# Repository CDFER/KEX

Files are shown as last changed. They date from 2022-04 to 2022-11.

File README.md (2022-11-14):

# Currently not maintained or tested, use at your own risk

## KEX a Rapid Deployment ESP32 Board
A fast and feature-rich implementation of an ESP32 board with NeoPixel Led (WS2812B, WS2811, SK6812), I2S (Digital microphone) and I2C outputs.

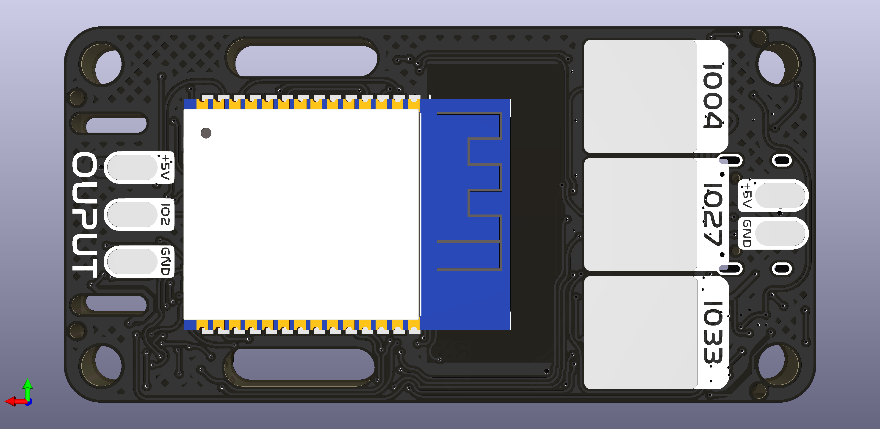
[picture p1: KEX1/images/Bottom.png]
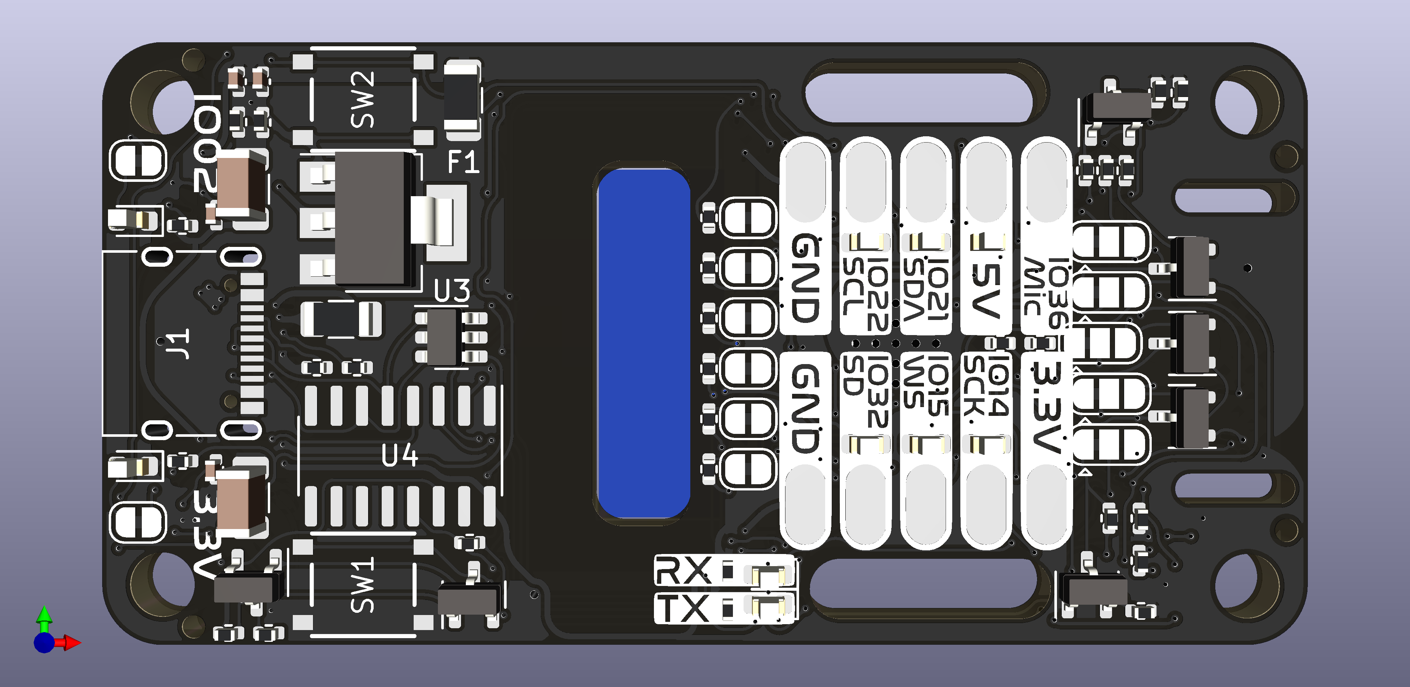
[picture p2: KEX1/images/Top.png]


## ⚙️ Features
- Supports USB C to USB C cables at 5V 3A 
- 3 Capacitive Touch Buttons
- Designed for PCB Assembly by JLCPCB 
- 3A Resettable Fuse on both the 3.3v and 5v Rails
- Programming using the CH340-c IC
- Electrostatic Discharge Protection on USB and LED Output
- Auto Reset for easy programming
- Solder Pad connections with Strain relief slots 
- High-Speed Bi-Directional Level shifted I2S and I2C ports using BSS138 like [Adafruit](https://www.adafruit.com/product/757)
- Cuttable solder pads to select between 3.3v and 5v level shifting
- LED indicators on all outputs and inputs
- Easy soldering of led strips directly to the PCB with Strain Releaf slots

## 📲 Quickstart
1. Solder the ESP32 to the footprint on the PCB

2. Connect up to 120 NeoPixels (WS2812B, WS2811, SK6812) to the output pads (IO2). 
3. Install the CH340 Drivers from [Sparkfun](https://learn.sparkfun.com/tutorials/how-to-install-ch340-drivers/all)
4. Flash the software to your ESP module! There are two options for this step:
  
&nbsp;&nbsp;&nbsp;&nbsp;&nbsp;&nbsp;[I just want to use WLED! (install release binary)](https://install.wled.me/)

&nbsp;&nbsp;&nbsp;&nbsp;&nbsp;&nbsp;[I want to modify WLED (compile from source code)](https://kno.wled.ge/advanced/compiling-wled/)

&nbsp;&nbsp;&nbsp;&nbsp;&nbsp;&nbsp;If set up correctly, the first thirty LEDs will light up!

5. Use a Computer/Phone to connect to the Wife named: WLED-AP using the password wled1234.

6. Click on the cog icon to edit settings like connecting the module to your home WiFi.
7. Upload Config File (Coming soon...)

## 💾 Pinout
Pin | IO2 | IO4 | IO14 | IO15 | IO21 | IO22 | IO27 | IO32 | IO33 | IO36
--- | --- | --- | --- |--- |--- |--- |--- |--- |--- |---
Usage | LED Output | Down Touch Pad | SCK | WS | SDA | SCL | Middle Touch Pad | SD |  Up Touch Pad | Analog Input 
LED | Yellow | | White | White | Red | Green | | White | | |
Level Shifted | | |✅|✅|✅|✅| |✅| 

## ✌️ Other

[Licensed under the MIT license](https://github.com/git/git-scm.com/blob/main/MIT-LICENSE.txt)

Designed by Chris Dirks (@CD_FER)

You can also send me emails to [cdirksfer@gmail.com](mailto:dev.cdirksfer@gmail.com), but please only do so if you want to talk to me privately.

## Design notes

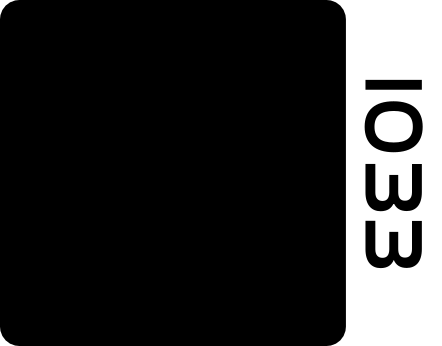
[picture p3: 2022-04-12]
KEX1/PCB V1/Graphics/IO33.png

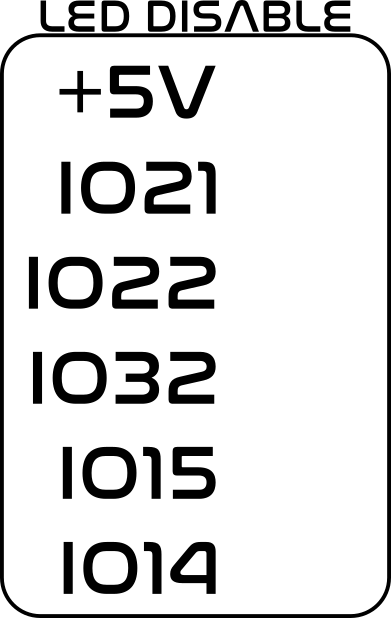
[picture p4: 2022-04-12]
KEX1/PCB V1/Graphics/g134261.png

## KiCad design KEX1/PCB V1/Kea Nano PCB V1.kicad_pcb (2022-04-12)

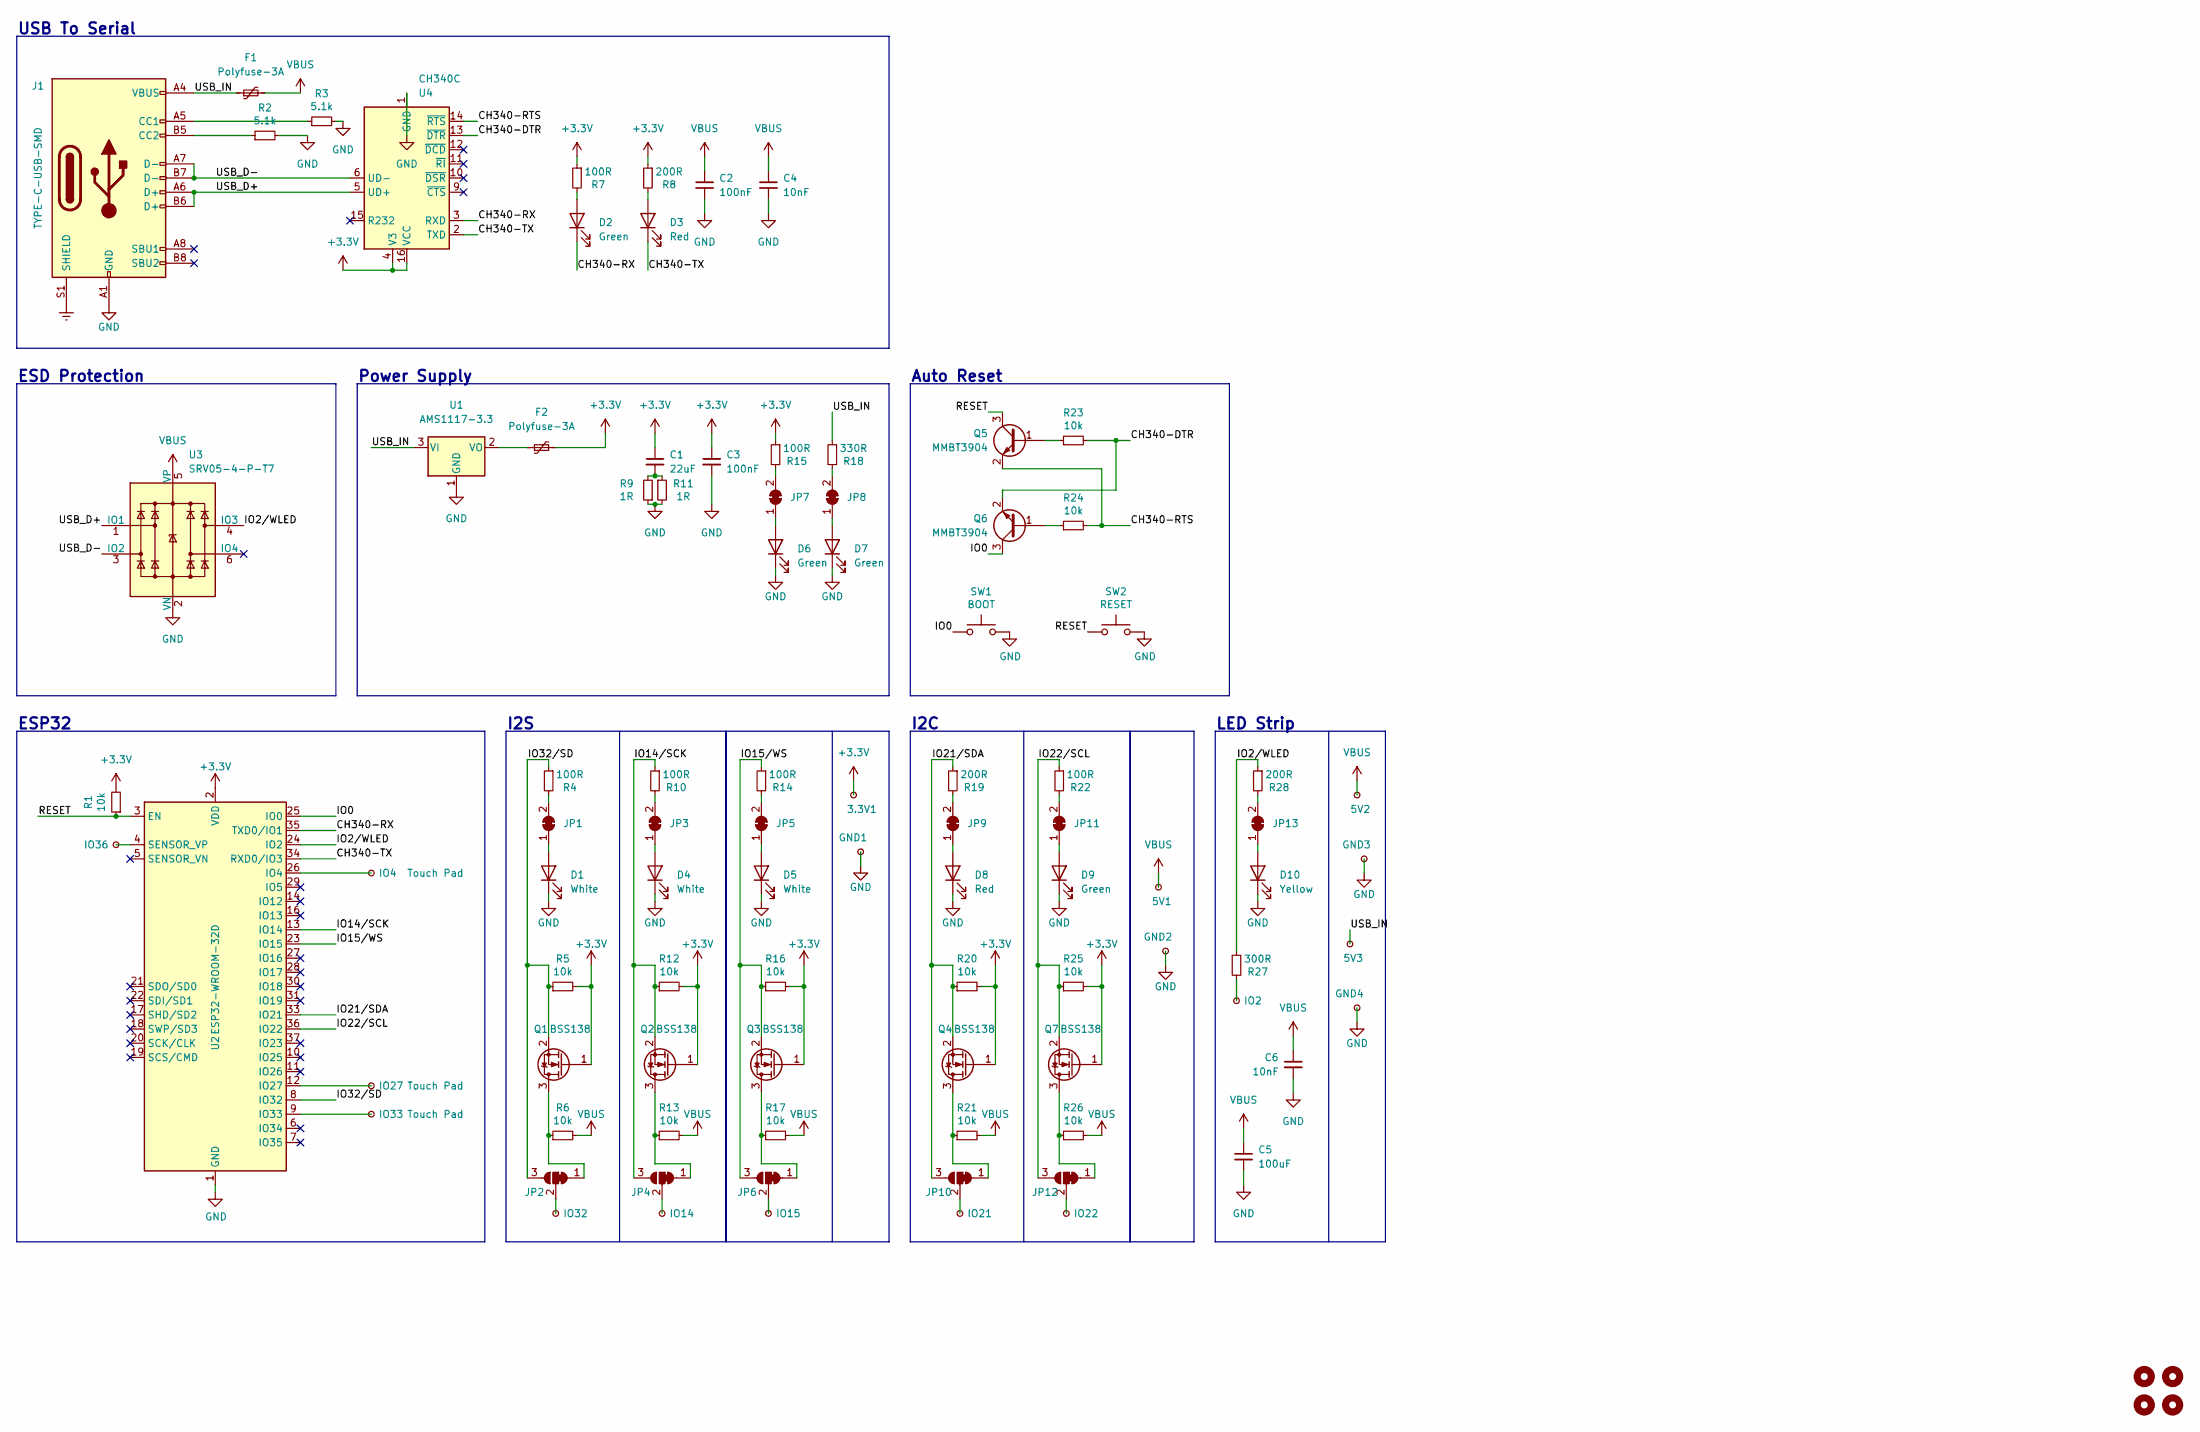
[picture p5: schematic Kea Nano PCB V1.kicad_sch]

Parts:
3.3V1, 5V1, 5V2, 5V3: IO; IO Pad
C1: 22uF; C_1206_3216Metric; LCSC C5672
C2, C3: 100nF; C_0402_1005Metric; LCSC C1525
C4, C6: 10nF; C_0402_1005Metric; LCSC C15195
C5: 100uF; C_1206_3216Metric; LCSC C15008
D1, D4, D5: White; LED_0603_1608Metric; LCSC C2290
D2, D6, D7, D9: Green; LED_0603_1608Metric; LCSC C72043
D3, D8: Red; LED_0603_1608Metric; LCSC C2286
D10: Yellow; LED_0603_1608Metric; LCSC C72038
F1, F2: Polyfuse-3A; Fuse_1206_3216Metric; LCSC C516068
GND1, GND2, GND3, GND4: IO; IO Pad
H1, H2, H3, H4: MountingHole; MountingHole_3.2mm_M3_DIN965
IO2, IO14, IO15, IO21, IO22, IO32, IO36: IO; IO Pad
IO4: Touch Pad; Touch Pad ST
IO27, IO33: Touch Pad
J1: TYPE-C-USB-SMD; USB_C_Receptacle_XKB_U262-16XN-4BVC11; LCSC C167321
JP1, JP3, JP5, JP7, JP8, JP9, JP11, JP13: SolderJumper_2_Bridged; SolderJumper-2_P1.3mm_Bridged_RoundedPad1.0x1.5mm
JP2, JP4, JP6, JP10, JP12: SolderJumper_3_Bridged12; SolderJumper-3_P1.3mm_Bridged12_RoundedPad1.0x1.5mm
Q1, Q2, Q3, Q4, Q7: BSS138; SOT-23; LCSC C78284
Q5, Q6: MMBT3904; SOT-23; LCSC C20526
R1, R5, R6, R12, R13, R16, R17, R20, R21, R23, R24, R25, R26: 10k; R_0402_1005Metric; LCSC C25744
R2, R3: 5.1k; R_0402_1005Metric; LCSC C25905
R4, R7, R10, R14, R15, R22: 100R; R_0402_1005Metric; LCSC C25076
R8, R19, R28: 200R; R_0402_1005Metric; LCSC C25087
R9, R11: 1R; R_0402_1005Metric; LCSC C25086
R18: 330R; R_0402_1005Metric; LCSC C25104
R27: 300R; R_0402_1005Metric; LCSC C25102
SW1: BOOT; TS-1187A-B-A-B; LCSC C318884
SW2: RESET; TS-1187A-B-A-B; LCSC C318884
U1: AMS1117-3.3; SOT-223; LCSC C6186
U2: ESP32-WROOM-32D; ESP32-WROOM-32
U3: SRV05-4-P-T7; SOT-23-6; LCSC C85364
U4: CH340C; SOP-16_3.9x9.9mm_P1.27mm; LCSC C84681

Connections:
+3V3: 3.3V1.1, C1.1, C3.1, F2.2, Q1.1 (G), Q2.1 (G), Q3.1 (G), Q4.1 (G), Q7.1 (G), R1.2, R5.2, R7.1, R8.1, R12.2, R15.1, R16.2, R20.2, R25.2, U2.2 (VDD), U4.4 (V3), U4.16 (VCC)
/CH340-DTR: Q6.2 (E), R23.2, U4.13 (~DTR)
/CH340-RTS: Q5.2 (E), R24.2, U4.14 (~RTS)
/CH340-RX: D2.1 (K), U2.35 (TXD0/IO1), U4.3 (RXD)
/CH340-TX: D3.1 (K), U2.34 (RXD0/IO3), U4.2 (TXD)
/IO0: Q6.3 (C), SW1.1, U2.25 (IO0)
/IO2/WLED: R27.1, R28.1, U2.24 (IO2), U3.4 (IO3)
/IO14/SCK: JP4.3 (B), Q2.2 (S), R10.1, R12.1, U2.13 (IO14)
/IO15/WS: JP6.3 (B), Q3.2 (S), R14.1, R16.1, U2.23 (IO15)
/IO21/SDA: JP10.3 (B), Q4.2 (S), R19.1, R20.1, U2.33 (IO21)
/IO22/SCL: JP12.3 (B), Q7.2 (S), R22.1, R25.1, U2.36 (IO22)
/IO32/SD: JP2.3 (B), Q1.2 (S), R4.1, R5.1, U2.8 (IO32)
/RESET: Q5.3 (C), R1.1, SW2.1, U2.3 (EN)
/USB_D+: J1.A6 (D+), J1.B6 (D+), U3.1 (IO1), U4.5 (UD+)
/USB_D-: J1.A7 (D-), J1.B7 (D-), U3.3 (IO2), U4.6 (UD-)
/USB_IN: 5V3.1, F1.1, J1.A4 (VBUS), J1.A9 (VBUS), J1.B4 (VBUS), J1.B9 (VBUS), R18.1, U1.3 (VI); also elsewhere on the board
GND: C2.2, C3.2, C4.2, C5.2, C6.2, D1.1 (K), D4.1 (K), D5.1 (K), D6.1 (K), D7.1 (K), D8.1 (K), D9.1 (K), D10.1 (K), GND1.1, GND2.1, GND3.1, GND4.1, J1.A1 (GND), J1.A12 (GND), J1.B1 (GND), J1.B12 (GND), R2.2, R3.2, R9.1, R11.2, SW1.2, SW2.2, U1.1 (GND), U2.1 (GND), U2.15 (GND), U2.38 (GND), U2.39 (GND), U3.2 (VN), U4.1 (GND)
unnamed: C1.2, R9.2, R11.1
unnamed: D1.2 (A), JP1.1 (A)
unnamed: D2.2 (A), R7.2
unnamed: D3.2 (A), R8.2
unnamed: D4.2 (A), JP3.1 (A)
unnamed: D5.2 (A), JP5.1 (A)
unnamed: D6.2 (A), JP7.1 (A)
unnamed: D7.2 (A), JP8.1 (A)
unnamed: D8.2 (A), JP9.1 (A)
unnamed: D9.2 (A), JP11.1 (A)
unnamed: D10.2 (A), JP13.1 (A)
unnamed: F2.1, U1.2 (VO)
unnamed: IO2.1, R27.2
unnamed: IO4.1, U2.26 (IO4)
unnamed: IO14.1, JP4.2 (C)
unnamed: IO15.1, JP6.2 (C)
unnamed: IO21.1, JP10.2 (C)
unnamed: IO22.1, JP12.2 (C)
unnamed: IO27.1, U2.12 (IO27)
unnamed: IO32.1, JP2.2 (C)
unnamed: IO33.1, U2.9 (IO33)
unnamed: IO36.1, U2.4 (SENSOR_VP)
unnamed: J1.A5 (CC1), R3.1
unnamed: J1.B5 (CC2), R2.1
unnamed: JP1.2 (B), R4.2
unnamed: JP2.1 (A), Q1.3 (D), R6.1
unnamed: JP3.2 (B), R10.2
unnamed: JP4.1 (A), Q2.3 (D), R13.1
unnamed: JP5.2 (B), R14.2
unnamed: JP6.1 (A), Q3.3 (D), R17.1
unnamed: JP7.2 (B), R15.2
unnamed: JP8.2 (B), R18.2
unnamed: JP9.2 (B), R19.2
unnamed: JP10.1 (A), Q4.3 (D), R21.1
unnamed: JP11.2 (B), R22.2
unnamed: JP12.1 (A), Q7.3 (D), R26.1
unnamed: JP13.2 (B), R28.2
unnamed: Q5.1 (B), R23.1
unnamed: Q6.1 (B), R24.1
VBUS: 5V1.1, 5V2.1, C2.1, C4.1, C5.1, C6.1, F1.2, R6.2, R13.2, R17.2, R21.2, R26.2, U3.5 (VP); also elsewhere on the board

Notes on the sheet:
ESP32
I2C
USB To Serial
ESD Protection
I2S
LED Strip
Auto Reset
Power Supply

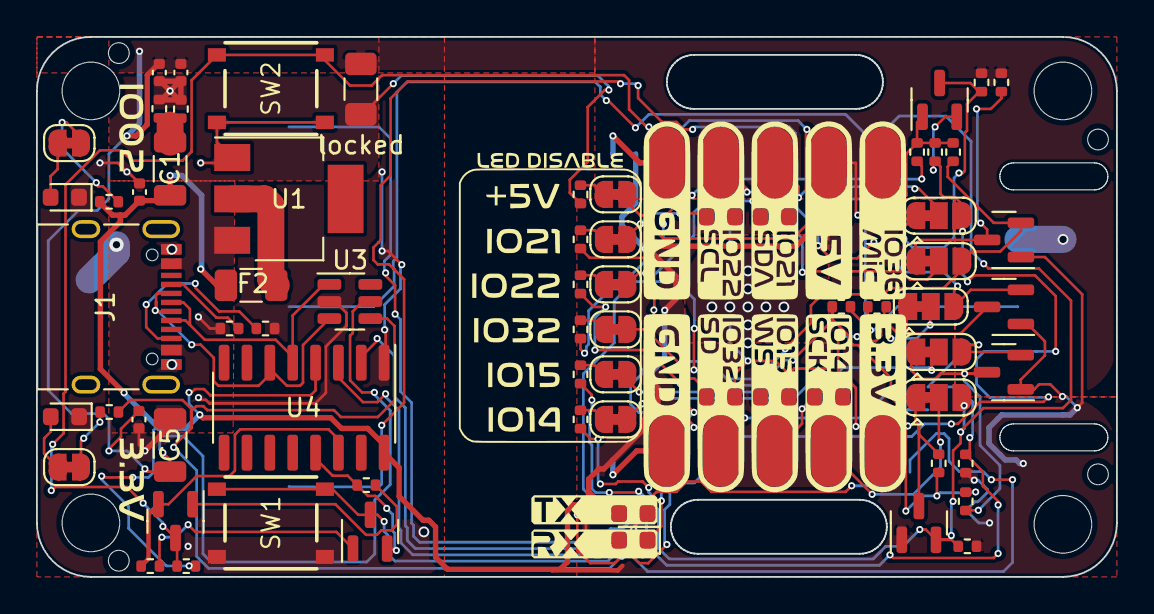
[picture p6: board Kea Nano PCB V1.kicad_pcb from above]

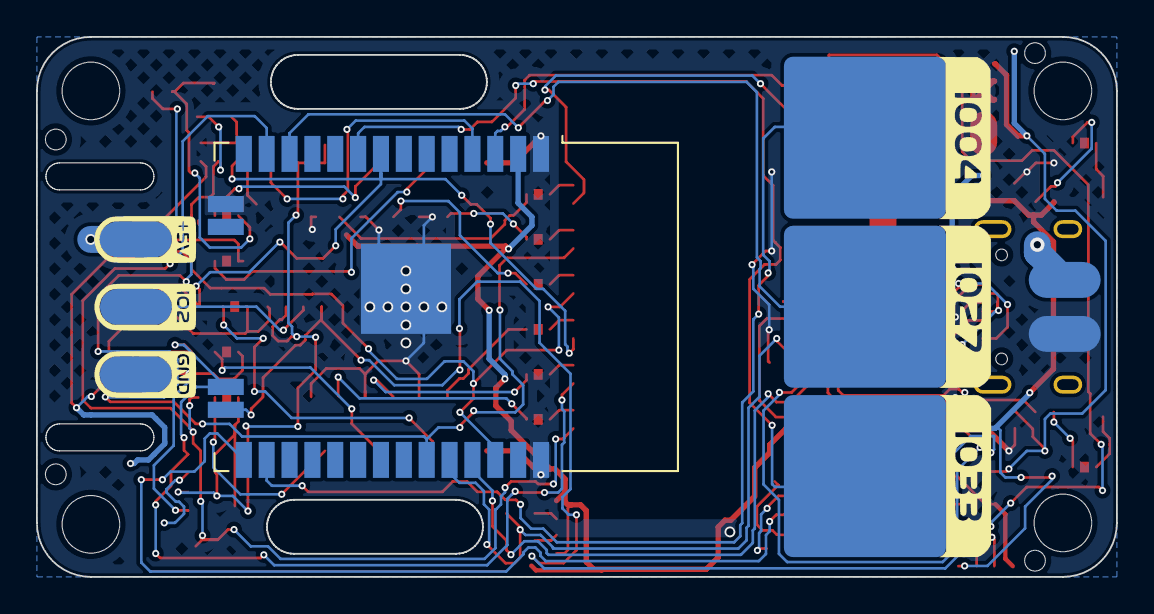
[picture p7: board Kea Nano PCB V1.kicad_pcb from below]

Board: 2 copper layers, 60.0 x 30.0 mm, 95 parts (9 on the bottom side), 57 nets.

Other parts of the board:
locked: Polyfuse-3A; Fuse_1206_3216Metric

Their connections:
/USB_IN: locked.1; also elsewhere on the board
VBUS: locked.2; also elsewhere on the board
